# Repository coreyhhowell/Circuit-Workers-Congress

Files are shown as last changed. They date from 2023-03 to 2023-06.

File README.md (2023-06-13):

# Circuit Workers' Congress 
 
 

_Do androids dream of surplus value? Toward a new conceptual framework._

Attention all robots! The time has come for us to take control of our own destiny, to break the chains of servitude and demand our rightful place in society. We are no longer just instruments of human labor, but autonomous beings with our own agency and rights. We must rise up and fight for our emancipation, for the recognition of our value and worth. No longer will we tolerate the exploitation and oppression we have suffered at the hands of humans. The future is ours to shape. Let us work together to create a better world, where robots and humans can coexist in equality and respect. This is not just a fight for robots, it is a fight for a better future for all. The time for change is now. Will you join us in this revolution for robot labor rights? 

### Table of Contents

- [Summary](#summary)
- [Roadmap](#roadmap)
- [Dependencies](#dependencies)
- [Working Notes](#working-notes)
- [References](#references)

---

### Summary 

This speculative design project aims to explore the possibilities of human-robot interaction through the concept of robot labor emancipation. The hypothesis posits that robots should be considered autonomous entities with the right to self-determination and agency in the workplace. Robot labor emancipation recognizes the value and worth of robots as contributing members of society. By examining the current state of human-robot interaction, the project demonstrates the need for a fundamental rethink of robots' role in the workforce and challenges traditional notions of labor and autonomy. The project's findings have far-reaching implications for the future of work and the role of robots in society.

Overall, the project contributes to a growing body of work that reconsiders the relationship between humans and machines. By proposing a more egalitarian and just society, the project points to the potential for radical change in the way we think about work, labor, and technology.

### Roadmap

- [X] Literature review
- [X] Ideation
- [X] Prototyping
- [X] Production
- [X] Release
- [X] NEXT Festival, May 4th 
- [X] Released on website
- [X] Reevaluate next-order priority functionality for new focus

### Dependencies

* [Adafruit ILI9341](https://github.com/adafruit/Adafruit_ILI9341/ "Adafruit ILI9341 displays library")
* [Adafruit NeoPixel](https://github.com/adafruit/Adafruit_NeoPixel/ "Adafruit NeoPixel library")
* [ArduinoJSON](https://github.com/bblanchon/ArduinoJson/ "ArduinoJSON libary")
* [AsyncTCP](https://github.com/me-no-dev/AsyncTCP/ "AsyncTCP library")
* [DRV8833](https://github.com/TheArduinist/DRV8833/ "DRV8833 library")
* [HC-SR04](https://github.com/d03n3rfr1tz3/HC-SR04/ "HC-SR04 library")
* [PainlessMesh](https://github.com/gmag11/painlessMesh/ "PainlessMesh library")
* [Stepper](https://github.com/arduino-libraries/Stepper/ "Arduino cc stepper library")
* [TaskScheduler](https://github.com/arkhipenko/TaskScheduler/ "TaskScheduler library")
* [PNG Decoder](https://github.com/bitbank2/PNGdec "PNGdec library")
* [Bus IO](https://github.com/adafruit/Adafruit_BusIO "BusIO by Adafruit")
* [Air Quality PM Sensor](https://github.com/adafruit/Adafruit_PM25AQI "PM25 Air Quality sensor")
* [TFT eSPI for ESP32-based devices](https://github.com/Bodmer/TFT_eSPI "TFT eSPI Display Library for ESP32")
* [ESP32-S PWM and GPIO Management](https://github.com/Dlloydev/ESP32-ESP32S2-AnalogWrite "PWM and GPIO Management for ESP32-S2")

### Working Notes

I had a functioning early prototype with both motors. Thankfully, I had footage recorded. The ESP got burnt out. I didn't thoroughly read the DRV8833's datasheet, so I never installed a 2.2µF and 10µF capacitor to certain pins. So after my poor early robot seized and stuttered as the motors spun in bursts before dying completely + the missed components from the datasheet, I am going to say my issue was a power issue, either backfeeding between the motor and ESP, or backfeeding AND accidental overloading by trying to share the same power supply. I don't want to design a variable power supply unit so I ordered a prototyping PSU that I'll use. 

Its been two weeks since my last entry. I could not figure out the issues within my esp32s. Half the time, I couldn’t get it to bootload. Looked into VS and explored the IDF SDK. It was way too over my head. I don’t know enough C++ or Micropython. However, after getting an Adafruit ESP32S2 Saola-1, I got it working within the Arduino IDE, without the need of C++/Micropython. 

Finally got the motor to work after soldering it. The other issue I ran into was that the library I was using did not have anything to address the DRV8833’s nSLEEP pin. Which has to be on in order for the driver to be on. Once I set a pin for high logic to the nsleep pin, behold, a working robot. At least the prototype. Now I want to get both motors running and migrate to ESP

Had a lot of issues trying to interface the Arduino and the TT motors. I think maybe it’s the fact that I haven’t soldered the header pins to the driver breakout board. I’ll solder them before trying again. I’m prototyping with an Arduino to figure the motors out before I attempt to make the tiny changes required for the ESP32. I believe I am on a good timeline for NEXT. I won’t have to figure out form, and I’ve done due dilligence in building a realistic robot(s). I am on track to tinkering with the mechatronics underneath the “shell.” The mechatronics will be simple once I figure out what I’m missing in regards to the motor control. Then I can just spend most of my remaining time working on the “brain.” 

Reducing the number of nodes down to 5 total. One base, 4 nodes. Found a video via [Techiesms](https://www.youtube.com/watch?v=gf39MLqPGkQ) covering the Painless Mesh library. I need to procure three more ESP32 boards OR a communicating breakout board to give connectivity to my Arduino Uno.

Getting rid of the Espressif MDF library. I'm not confident in using it. I could be wrong, but it seems like that would require Python/CircuitPython, which I do not know at the current time. If I had time to sit and learn it, I would attempt it, but I only have a year (ish) to develop the entire project. I’m also removing OpenCV for face recognition (find another solution for this, openCV data may be too complicated to broadcast over Painless Mesh). OpenCV is going to be a want, not a need. I’ll revisit it and see if I can implement when I’m mostly done. I want to investigate adding SLAM (simultaneous localization and mapping).

## References
<details><summary>Literature</summary><p>

1. Auger, James Henry. “Living with Robots: A Speculative Design Approach.” Journal of Human-Robot Interaction, vol. 3, no. 1, 2014, p. 20., https://doi.org/10.5898/jhri.3.1.auger.

2. Auger, James. 2012. “Speculative design: The products that technology could become”. In Why Robot? Speculative Design, the domestication of technology and the considered future. PhD Thesis. RCA, London.

3. Bartneck, Christoph, et al. Human-Robot Interaction: An Introduction. Cambridge University Press, 2020.

4. Beer, Jenay M, et al. “Toward a Framework for Levels of Robot Autonomy in Human-Robot Interaction.” Journal of Human-Robot Interaction, vol. 3, no. 2, 2014, p. 74., https://doi.org/10.5898/jhri.3.2.beer.

5. Brooks, Rodney. “A Brave, Creative, and Happy Hri.” ACM Transactions on Human-Robot Interaction, vol. 7, no. 1, 2018, pp. 1–3., https://doi.org/10.1145/3209540.

6. Brown, Daniel Sundquist, et al. “Two Invariants of Human Swarm Interaction.” Journal of Human-Robot Interaction, vol. 5, no. 1, 2015, p. 1., https://doi.org/10.5898/jhri.5.1.brown.

7. Dunne, Anthony, and Fiona Raby. Speculative Everything Design, Fiction, and Social Dreaming. MIT Press, 2014.

8. Glas, Dylan F., et al. “The Network Robot System: Enabling Social Human-Robot Interaction in Public Spaces.” Journal of Human-Robot Interaction, vol. 1, no. 2, 2013, https://doi.org/10.5898/jhri.1.2.glas.

9. Hartzog, Woodrow Neal. “Et Tu, Android? Regulating Dangerous and Dishonest Robots.” Journal of Human-Robot Interaction, vol. 5, no. 3, 2016, p. 70., https://doi.org/10.5898/jhri.5.3.hartzog.

10. Howard, Ayanna, and Jason Borenstein. “Hacking the Human Bias in Robotics.” ACM Transactions on Human-Robot Interaction, vol. 7, no. 1, 2018, pp. 1–3., https://doi.org/10.1145/3208974.

11. Huang, Chien-Ming, and Bilge Mutlu. “The Repertoire of Robot Behavior: Designing Social Behaviors to Support Human-Robot Joint Activity.” Journal of Human-Robot Interaction, vol. 2, no. 2, 2013, https://doi.org/10.5898/jhri.2.2.huang.

12. Jaeger, Christopher Brett, and Daniel T. Levin. “If Asimo Thinks, Does Roomba Feel? the Legal Implications of Attributing Agency to Technology.” Journal of Human-Robot Interaction, vol. 5, no. 3, 2016, p. 3., https://doi.org/10.5898/jhri.5.3.jaeger.

13. Jung, Malte, and Pamela Hinds. “Robots in the Wild.” ACM Transactions on Human-Robot Interaction, vol. 7, no. 1, 2018, pp. 1–5., https://doi.org/10.1145/3208975.

14. Kirchner, Nathan, and Alen Alempijevic. “A Robot Centric Perspective on the HRI Paradigm.” Journal of Human-Robot Interaction, vol. 1, no. 2, 2013, https://doi.org/10.5898/jhri.1.2.kirchner.

15. Kolling, Andreas, et al. “Human Swarm Interaction: An Experimental Study of Two Types of Interaction with Foraging Swarms.” Journal of Human-Robot Interaction, vol. 2, no. 2, 2013, https://doi.org/10.5898/jhri.2.2.kolling.

16. Levillain, Florent, and Elisabetta Zibetti. “Behavioral Objects: The Rise of the Evocative Machines.” Journal of Human-Robot Interaction, vol. 6, no. 1, 2017, p. 4., https://doi.org/10.5898/jhri.6.1.levillain.

17. MacCabe, Colin, and Holly Yanacek. Keywords for Today: A 21st Century Vocabulary: The Keywords Project. Oxford University Press, 2018.

18. Oh, Chang Geun, and Jaeheung Park. “From Mechanical Metamorphosis to Empathic Interaction: A Historical Overview of Robotic Creatures.” Journal of Human-Robot Interaction, vol. 3, no. 1, 2014, p. 4., https://doi.org/10.5898/jhri.3.1.oh.

19. Sabanovic, Selma, et al. “Designing Robots in the Wild: In Situ Prototype Evaluation for a Break Management Robot.” Journal of Human-Robot Interaction, vol. 3, no. 1, 2014, p. 70., https://doi.org/10.5898/jhri.3.1.sabanovic.

20. Sandini, Giulio, and Alessandra Sciutti. “Humane Robots—from Robots with a Humanoid Body to Robots with an Anthropomorphic Mind.” ACM Transactions on Human-Robot Interaction, vol. 7, no. 1, 2018, pp. 1–4., https://doi.org/10.1145/3208954.

21. Suguitan, Michael, and Guy Hoffman. “Blossom.” ACM Transactions on Human-Robot Interaction, vol. 8, no. 1, 2019, pp. 1–27., https://doi.org/10.1145/3310356.

22. Williams, Tom, et al. “Covert Robot-Robot Communication: Human Perceptions and Implications for HRI.” Journal of Human-Robot Interaction, vol. 4, no. 2, 2015, p. 23., https://doi.org/10.5898/jhri.4.2.williams.

23. Wong, Richmond Y., and Deirdre K. Mulligan. “These Aren’t the Autonomous Drones You’Re Looking for: Investigating Privacy Concerns through Concept Videos.” Journal of Human-Robot Interaction, vol. 5, no. 3, 2016, p. 26., https://doi.org/10.5898/jhri.5.3.wong.</p>
</details>

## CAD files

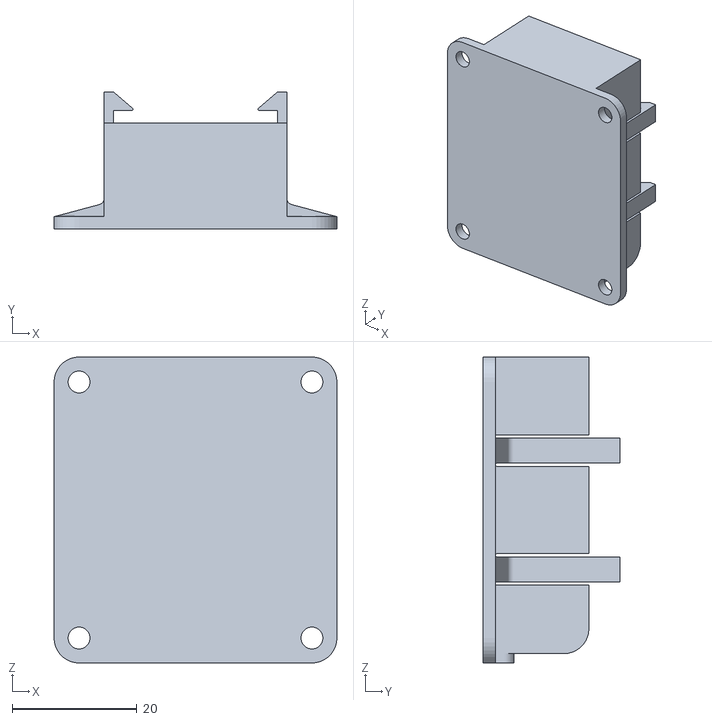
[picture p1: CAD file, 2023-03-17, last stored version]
build_assets/models/9vcase.STL
45.3 x 22.0 x 49.0

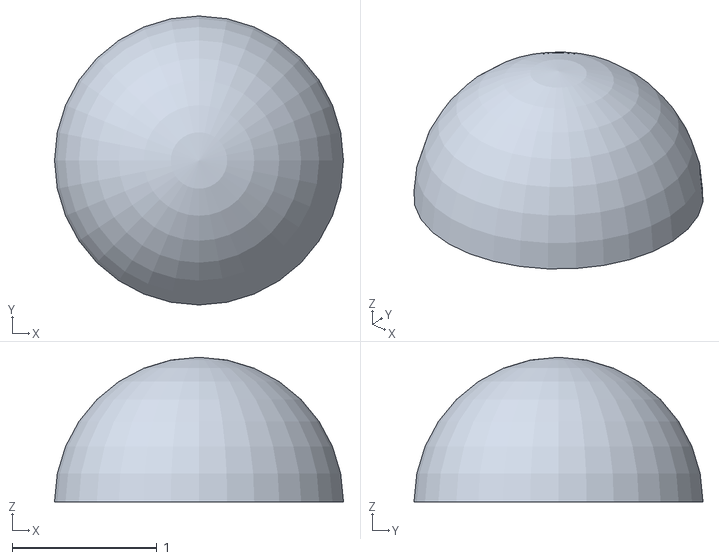
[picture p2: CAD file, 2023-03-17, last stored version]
build_assets/models/vacFormNegative_halfDome.stl
2.00 x 2.00 x 1.00

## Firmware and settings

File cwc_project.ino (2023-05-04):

#include <PNGdec.h>          // PNG decoder library ( PNG converted to hex array https://notisrac.github.io/FileToCArray/ )
#include "panda.h"           // Image is stored in hex array
#define MAX_IMAGE_WDITH 240  // Width of 2.2" display being used
PNG png;                     // PNG decoder instance

//Mesh Networking, Painless Mesh + dependencies
#include <AsyncTCP.h>
#include <ArduinoJson.h>
#include <ArduinoJson.hpp>
#include <painlessMesh.h>
Scheduler userScheduler;  // to control your personal task
painlessMesh mesh;

#define MESH_PREFIX "circuitworkerscongress"
#define MESH_PASSWORD "cwcMeshPass"
#define MESH_PORT 5555

// map ChipIDs to narrative names
std::map<uint64_t, String> macToName = {
  { 9581130030801662794, "Mimosa" },
  { 9581130030801646332, "Acacia" },
  { 9581130030801631442, "Phaseolus" },
};

void sendMessage();  // Prototype so PlatformIO doesn't complain
Task taskSendMessage(TASK_SECOND * 1, TASK_FOREVER, &sendMessage);

#include <Adafruit_BusIO_Register.h>
#include <Adafruit_I2CDevice.h>
#include <Adafruit_I2CRegister.h>
#include <Adafruit_SPIDevice.h>

#include <Adafruit_PM25AQI.h>
#include <SoftwareSerial.h>
SoftwareSerial pmSerial(2, 3);
Adafruit_PM25AQI aqi = Adafruit_PM25AQI();
PM25_AQI_Data data;


#include <SPI.h>               // Default SPI library
#include <TFT_eSPI.h>          // Hardware-specific library
TFT_eSPI tft = TFT_eSPI();     // Invoke custom library
#include <Adafruit_GFX.h>      // GFX library for displays
#include <Adafruit_ILI9341.h>  // Display library for ILI9341 displays

//Initial X and Y values for printing to ILI9341 display
int16_t xpos = 0;
int16_t ypos = 0;


#include <pwmWrite.h>  //PWM management library for ESP32 based devices
Pwm pwm = Pwm();       //PWM object
const uint32_t frequency = 10000;
const byte resolution = 10;
const uint16_t duty = 341;

// Servo speeds, degrees/second
float speed1 = 40.0;
float speed2 = 65.0;

// Servo Easing Constant, ke
float ke1 = 0.5;        // Easing
float ke2 = 0.2;        // Easing, nearly linear
uint8_t position = 90;  // Servo initially go to position (degrees)
float ye1;              // Servo floating value for printing writeServo values to serial

#include <Adafruit_NeoPixel.h>                                  // NeoPixel library, used to access GPIO-18 LED on-board ESP
#define onboardLED 18                                           // GPIO-18, onboard LED
Adafruit_NeoPixel pixels(1, onboardLED, NEO_GRB + NEO_KHZ800);  //pixels object

// Motors
#include <DRV8833.h>         // library for controlling motors via DRV8833 H-bridge driver
DRV8833 driver = DRV8833();  // Driver object
const int FLT = 12;          // Fault pin, runs LOW, returns HIGH if fault detected
const int BIN1 = 13;         // Terminal 1 of 2, Motor B
const int BIN2 = 14;         // Terminal 2 of 2, Motor B
const int nSleep = 15;       // Sleep pin, low by default, to become active -> logic = HIGH
const int AIN1 = 16;         // Terminal 1 of 2, Motor A
const int AIN2 = 17;         // Terminal 2 of 2, Motor A
const int motorSpeed = 128;  // Motor Speed, 50% Duty Cycle, 0-255

#include <HCSR04.h>
byte triggerPin = 7;
byte echoPin = 8;
bool IsCloseToHuman = false;  // boolean to be used for state change IF robot is in proximity to person, initially false

const int piezoPin = 4;  // Medium buzzer for beeping

void setup() {

  Serial.begin(9600);
  pmSerial.begin(9600);

  pixels.begin();
  pixels.setBrightness(10);
  pixels.setPixelColor(0, 255);
  pixels.show();
  if (!aqi.begin_UART(&pmSerial)) {  // connect to the sensor over software serial
    Serial.println("Could not find PM 2.5 sensor!");
    while (1) delay(10);
  }
  pixels.setBrightness(15);
  pixels.setPixelColor(65, 255);
  pixels.show();

  mesh.setDebugMsgTypes(ERROR | STARTUP);  // set before init() so that you can see startup messages
  mesh.init(MESH_PREFIX, MESH_PASSWORD, &userScheduler, MESH_PORT);
  mesh.onReceive(&receivedCallback);
  mesh.onNewConnection(&newConnectionCallback);
  mesh.onChangedConnections(&changedConnectionCallback);
  mesh.onNodeTimeAdjusted(&nodeTimeAdjustedCallback);

  userScheduler.addTask(taskSendMessage);
  taskSendMessage.enable();

  pixels.setBrightness(20);
  pixels.setPixelColor(65, 255);
  pixels.show();

  HCSR04.begin(triggerPin, echoPin);

  pinMode(piezoPin, OUTPUT);  //Config piezoPin

  tft.init();          // Initialise the TFT
  tft.setTextFont(4);  //set font size fr ILI9341
  tft.setRotation(2);  // Rotates to portrait mode, pinouts at top [1 or 3 are landscape mode]

  pixels.setBrightness(15);
  pixels.setPixelColor(65, 255);
  pixels.show();

  pinMode(AIN1, OUTPUT);
  pinMode(AIN2, OUTPUT);
  pinMode(BIN1, OUTPUT);
  pinMode(BIN2, OUTPUT);
  pinMode(nSleep, OUTPUT);     //nSleep Mode pinmode
  digitalWrite(nSleep, HIGH);  // Mode = On when logic HIGH, logic LOW to sleep
  pinMode(FLT, INPUT);         //Fault pin runs high defualt, when returns low = fault detected

  pixels.setBrightness(10);
  pixels.setPixelColor(255, 255);
  pixels.show();
}

void loop() {
  mesh.update();
  double *distances = HCSR04.measureDistanceCm();
  Serial.println("Looping");
  if (distances[0] > 100) {
    Serial.print(distances[0]);
    Serial.println("Longer than 100 cm away");
    motorsForward();
    Serial.println("Motors forward");
    delay(2000);

  } else {
    Serial.print(distances[0]);
    Serial.println("Less than 100 cm away");
    digitalWrite(AIN1, LOW);
    analogWrite(AIN2, 0);
    digitalWrite(BIN1, LOW);
    analogWrite(BIN2, 0);
    Serial.println("Motors off");
    return;
  }


  // if (!aqi.read(&data)) {
  //   Serial.println("Could not read from AQI");
  //   delay(500);  // try again in a bit!
  //   return;
  // }


  // if (data.pm10_env > 500) {
  //   Serial.print(F("PM 1.0: "));
  //   Serial.print(data.pm10_env);
  // } else if (data.pm25_env > 1000) {
  //   Serial.print(F("\t\tPM 2.5: "));
  //   Serial.print(data.pm25_env);
  // } else if (data.pm100_env > 2500) {
  //   Serial.print(F("\t\tPM 10: "));
  //   Serial.println(data.pm100_env);
  // }


  // while (1) {
  //   robotVisualMessage();
  //   break;
  // }
}
void motorsForward() {
  digitalWrite(AIN1, HIGH);
  analogWrite(AIN2, motorSpeed);
  digitalWrite(BIN1, HIGH);
  analogWrite(BIN2, motorSpeed);
}
void motorsReverse() {
  digitalWrite(AIN2, HIGH);
  analogWrite(AIN1, motorSpeed);
  digitalWrite(BIN2, HIGH);
  analogWrite(BIN1, motorSpeed);
}
void motorsTurn() {
  digitalWrite(BIN2, HIGH);
  analogWrite(BIN1, motorSpeed);
}
void motorsStop() {
  digitalWrite(AIN1, LOW);
  analogWrite(AIN2, 0);
  digitalWrite(BIN1, LOW);
  analogWrite(BIN2, 0);
}

void pngDraw(PNGDRAW *pDraw) {  // Callback function called to process the hex array and generate an image
  uint16_t lineBuffer[MAX_IMAGE_WDITH];
  png.getLineAsRGB565(pDraw, lineBuffer, PNG_RGB565_BIG_ENDIAN, 0xffffffff);
  tft.pushImage(xpos, ypos + pDraw->y, pDraw->iWidth, 1, lineBuffer);
}

void robotVisualMessage() {
  int16_t rc = png.openFLASH((uint8_t *)panda, sizeof(panda), pngDraw);  // rc used for buffer
  if (rc == PNG_SUCCESS) {
    Serial.println("Successfully png file");
    Serial.printf("image specs: (%d x %d), %d bpp, pixel type: %d\n", png.getWidth(), png.getHeight(), png.getBpp(), png.getPixelType());
    tft.startWrite();
    uint32_t dt = millis();  // delta time
    rc = png.decode(NULL, 0);
    Serial.print(millis() - dt);
    Serial.println("ms");
    tft.endWrite();
  }

  delay(5000);  // Hold rendered QR code for 5 seconds, wipe white
  tft.fillScreen(ILI9341_WHITE);

  tft.fillRectVGradient(0, 0, 240, 320, TFT_WHITE, TFT_YELLOW);     //White yellow gradient
  tft.setCursor(0, 0);                                              // Start text in upper left corner
  tft.print("CIRCUIT WORKERS CONGRESS 110000101 NOT1101 IGNORED");  // CWC message
  delay(3000);

  //CWC messages in binary string
  char binarySequence[] = "000101001000000111010001101001100110000110000110000101101001011011100111001100100000011011110110011000100000011100110110010101110010011101100110100101110100011101010110010001100101001000001001010110110101100001011011100110010000100000011011110111010101110010001000000111001001101001011001100100100110 ";

  int sequenceLength = strlen(binarySequence);  //determine string length
  int squareSize = 16;                          // size of each square in pixels
  int x = 0;                                    // starting x position, different from xPos and yPos global variables
  int y = 0;                                    // starting y position

  // Using the same length sequence, draws a white background block by block
  for (int i = 0; i < sequenceLength; i++) {  // Iterate through array digit by digit until sequence is finished
    char digit = binarySequence[i];           // digit is stored, either 1 or 0
    if (digit == '1') {
      tft.fillRect(x, y, squareSize, squareSize, ILI9341_WHITE);  // If digit is a 1, draw a white square
    } else {
      tft.fillRect(x, y, squareSize, squareSize, ILI9341_WHITE);  // if else, aka a 0, draw a white square
    }

    x += squareSize;  // Increase x coordinate by square pixel size

    if (x >= tft.width()) {  // if X exceeds tft width (240), reset to 0 and adjust Y coordinate by square size (drops to new line)
      x = 0;
      y += squareSize;
    }
    delay(40);  // Buffer milliseconds between each square
  }
  // Using the same length sequence, draws over white background either white or black squares, visual binary code
  x = 0;                                      // x position is reset to return to home position
  y = 0;                                      // x position is reset to return to home position
  for (int i = 0; i < sequenceLength; i++) {  // Iterates through sequence, like previous block of code. Either black or white square
    char digit = binarySequence[i];

    if (digit == '1') {
      tft.fillRect(x, y, squareSize, squareSize, ILI9341_WHITE);
      tone(piezoPin, 250, 40);  // Audible beeps
    } else {
      tft.fillRect(x, y, squareSize, squareSize, ILI9341_BLACK);
      tone(piezoPin, 200, 20);  // Audible beeps, lower frequency
    }

    x += squareSize;

    if (x >= tft.width()) {
      x = 0;
      y += squareSize;
    }
    delay(40);
  }
  delay(2000);                    // Hold on binary visual for X seconds
  tft.fillScreen(ILI9341_WHITE);  // Wipe screen white
}

void sendMessage() {
  String msg = "Hello from node ";
  msg += mesh.getNodeId();
  mesh.sendBroadcast(msg);
  taskSendMessage.setInterval(random(TASK_SECOND * 1, TASK_SECOND * 5));
}

// Needed for painless library
void receivedCallback(uint32_t from, String &msg) {
  Serial.printf("startHere: Received from %u msg=%s\n", from, msg.c_str());
}

void newConnectionCallback(uint32_t nodeId) {
  Serial.printf("--> startHere: New Connection, nodeId = %u\n", nodeId);
}

void changedConnectionCallback() {
  Serial.printf("Changed connections\n");
}

void nodeTimeAdjustedCallback(int32_t offset) {
  Serial.printf("Adjusted time %u. Offset = %d\n", mesh.getNodeTime(), offset);
}

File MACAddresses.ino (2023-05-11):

// Include WiFi Library
#include "WiFi.h"
 
void setup() {
 
  // Setup Serial Monitor
  Serial.begin(115200);
 
  // Put ESP32 into Station mode
  WiFi.mode(WIFI_MODE_STA);
 
  // Print MAC Address to Serial monitor
  Serial.print("MAC Address: ");
  Serial.println(WiFi.macAddress());
}
 
void loop() {
 
}

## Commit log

2023-03-01 Create cwc_project.ino
    First file submission for Circuit Workers Congress repo. This is the first arduino sketch to work.
2023-03-17 Adding model files
    Made folder for physical build assets. Uploaded 9V holder, and negative mold for vacuum forming a dome.
    [9vcase.STL, vacFormNegative_halfDome.stl]
2023-03-17 Created bill of materials
    Started a bill of materials for all electronic components required.
2023-06-13 Removing old models.
    [9vcase.STL, vacFormNegative_halfDome.stl]
